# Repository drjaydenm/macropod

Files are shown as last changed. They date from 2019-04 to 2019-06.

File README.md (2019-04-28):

# macropod

A basic macro keyboard built from the ground up

## Configuring Macros

To setup your own macro bindings, create a file `key_mappings.h` in the `code/src` directory with the below format. This file will be automatically detected and included in the build.

When editing, be sure to do a clean build to ensure headers are re-included.

```c
#ifndef __KEY_MAPPINGS_H
#define __KEY_MAPPINGS_H

// This will generate a unique GUID following the V4 spec
#define MACRO_KEY_0  GenerateGuid(MacroContext);WriteString(MacroContext, "\e")

// These output the given string
#define MACRO_KEY_1  WriteString(MacroContext, "Macro 1\n")
#define MACRO_KEY_2  GenerateGuid(MacroContext);WriteString(MacroContext, "\e\nMacro 2");
#define MACRO_KEY_3  WriteString(MacroContext, "\t\tMacro 3")
// And so on for the rest of the keys...

#endif
```

## Setup

### Install the GNU Toolchain for ARM Embedded Processors

The toolchain is required to compile for the STM32 target platform

#### MacOS

```bash
brew tap osx-cross/arm

brew install arm-gcc-bin
```

If you are using ST-Link

```bash
brew install stlink
```

If using J-Link, you also need to install the J-Link tools. You can download them from Segger here https://www.segger.com/downloads/jlink/#J-LinkSoftwareAndDocumentationPack

## Building

Run the build

```bash
make
```

Flash to device using ST-Link

```bash
make flash-stlink
```

or using J-Link

```bash
make flash-jlink
```

Inspect memory layout of image

```bash
arm-none-eabi-nm main.elf
```

## Debugging with GDB

### ST-Link GDB Server

```bash
st-util
```

### J-Link GDB Server

```bash
JLinkGDBServer -if swd -device STM32F042K6 -port 4242
```

### GDB

```bash
cd ./code

arm-none-eabi-gdb main.elf

target extended-remote :4242

load

continue

Ctrl^C

info registers

stepi

info registers

quit
```

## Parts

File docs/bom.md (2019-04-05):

| Part | Quantity | Part No. | Price | Link |
| --- | --- | --- | --- | --- |
| STM32F042K6T6 | 1 | 497-14647-ND | $4.15 | https://www.digikey.com.au/product-detail/en/stmicroelectronics/STM32F042K6T6/497-14647-ND/4815294 |
| 1N4148W-TP Diode | 20 | 1N4148WTPMSCT-ND | $0.125 | https://www.digikey.com.au/product-detail/en/micro-commercial-co/1N4148W-TP/1N4148WTPMSCT-ND/717311 |
| Cherry MX Blue | 20 | MX1A-E1NA | $10 per 10 | https://mechanicalkeyboards.com/shop/index.php?l=product_detail&p=4450 |
| DSA Key Caps | 20 | | | https://www.aliexpress.com/item/MP-1U-DSA-keys-PBT-Blank-Keycap-Mixded-Color-Cherry-MX-switch-keycaps-for-Wired-USB/32847751930.html |
| LED SMD Blue | 1 | 732-4982-1-ND | $0.18 | https://www.digikey.com.au/product-detail/en/wurth-electronics-inc/150080BS75000/732-4982-1-ND/4489910 |
| JTAG 10 Pin 1.27mm | 1 | 609-3695-1-ND | $1.23 | https://www.digikey.com.au/product-detail/en/amphenol-icc-fci/20021121-00010C4LF/609-3695-1-ND/2209147 |
| 5.6Ohm Resistor | 1 | P5.6ACT-ND | $0.15 | https://www.digikey.com.au/product-detail/en/panasonic-electronic-components/ERJ-6GEYJ5R6V/P5.6ACT-ND/282468 |
| 0.1uF Capacitor | 3 | 1276-1099-1-ND | $0.15 | https://www.digikey.com.au/product-detail/en/samsung-electro-mechanics/CL21B104KACNNNC/1276-1099-1-ND/3889185 |
| 4.7uF Capacitor | 2 | 1276-6464-1-ND | $0.19 | https://www.digikey.com.au/product-detail/en/samsung-electro-mechanics/CL21A475KPFNNNG/1276-6464-1-ND/5958092 |
| USB Micro B Connector | 1 | WM11262CT-ND | $2.35 | https://www.digikey.com.au/product-detail/en/molex/1050171001/WM11262CT-ND/3313406 |
| 3.3V Regulator | 1 | 497-17239-1-ND | $0.66 | https://www.digikey.com.au/product-detail/en/stmicroelectronics/LDL1117S33R/497-17239-1-ND/7102079 |
| Tactile Switch | 1 | SW1020CT-ND | $1.47 | https://www.digikey.com.au/product-detail/en/omron-electronics-inc-emc-div/B3U-1000P/SW1020CT-ND/1534357 |
| Bumper Feet | 4 | SJ5003-0-ND | $7.83 per 56 | https://www.digikey.com.au/product-detail/en/3m/SJ-5003-BLACK/SJ5003-0-ND/102573 |

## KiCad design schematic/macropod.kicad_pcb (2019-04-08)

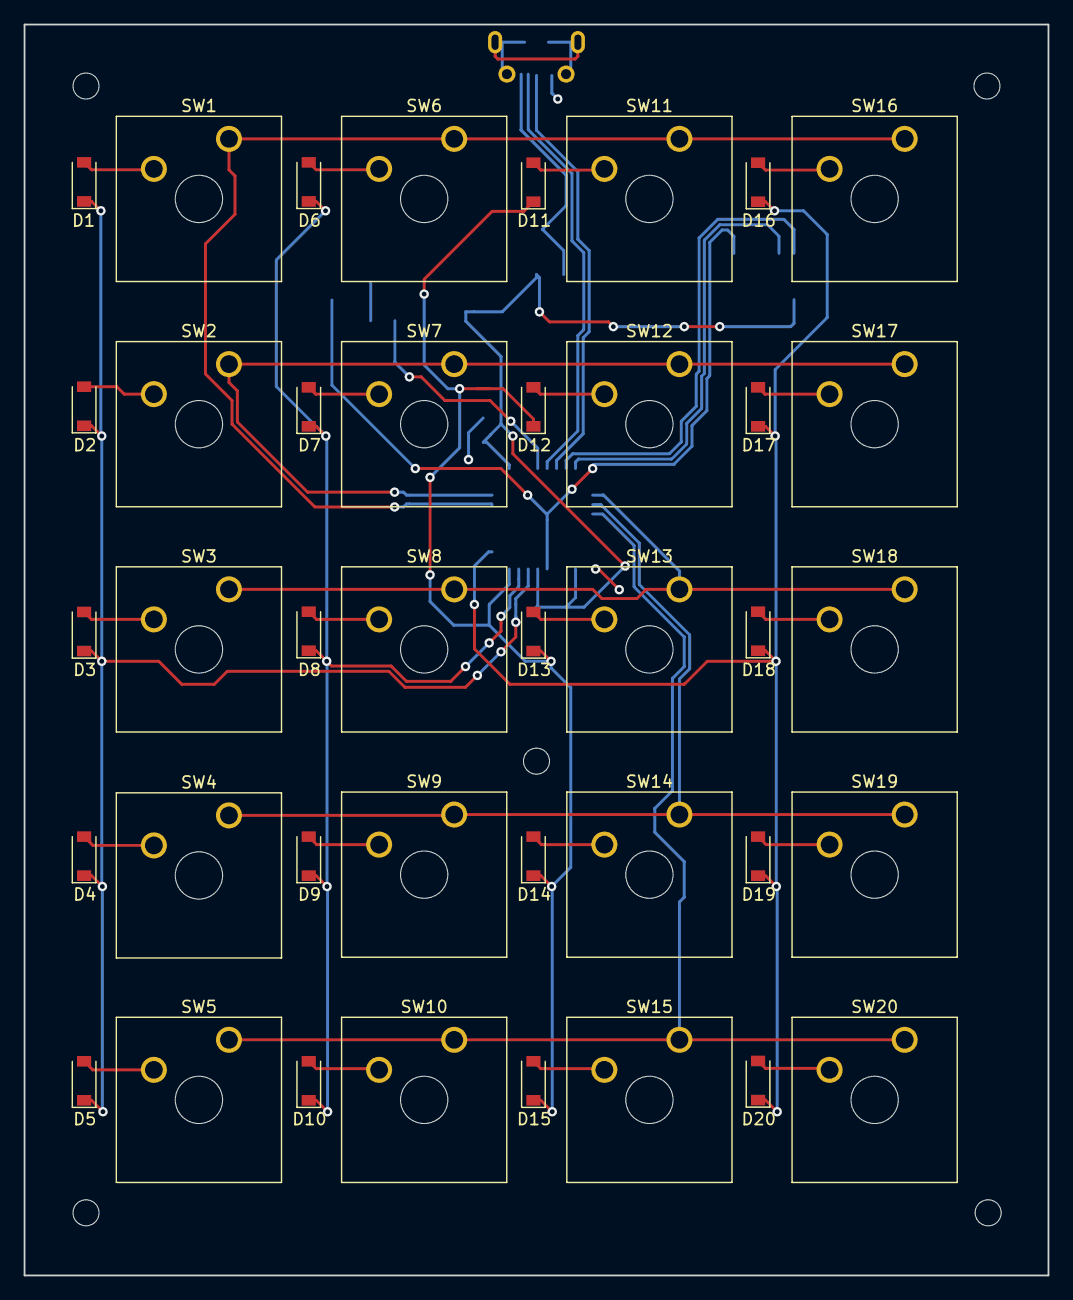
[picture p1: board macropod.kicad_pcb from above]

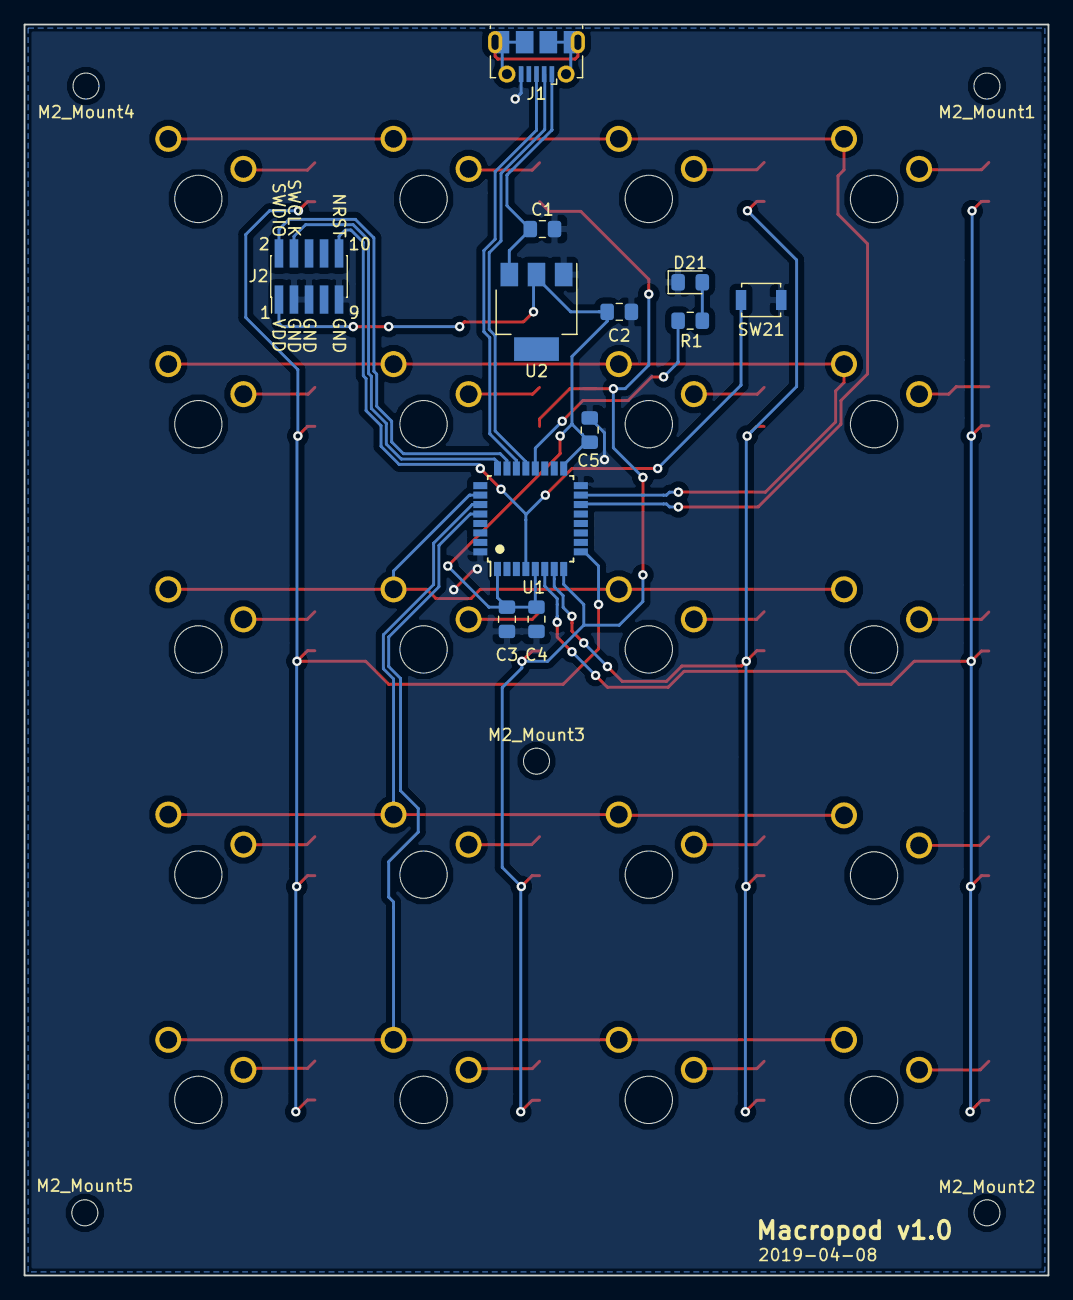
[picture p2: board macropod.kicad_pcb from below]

Board: 2 copper layers, 86.6 x 105.8 mm, 57 parts (17 on the bottom side), 39 nets.

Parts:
C1, C2: 4.7uF; C_0805_2012Metric_Pad1.15x1.40mm_HandSolder
C3, C4, C5: 100nF; C_0805_2012Metric_Pad1.15x1.40mm_HandSolder
D1, D2, D3, D4, D5, D6, D7, D8, D9, D10, D11, D12, D13, D14, D15, D16, D17, D18, D19, D20: D; D_SOD-123
D21: LED; LED_0805_2012Metric_Pad1.15x1.40mm_HandSolder
J1: USB_B_Micro; USB_Micro-B_Molex-105017-0001
J2: Conn_ARM_JTAG_SWD_10; PinHeader_2x05_P1.27mm_Vertical_SMD
M2_Mount1, M2_Mount2, M2_Mount3, M2_Mount4, M2_Mount5: MountingHole_2.2mm_M2
R1: 470; R_0805_2012Metric_Pad1.15x1.40mm_HandSolder
SW1, SW2, SW3, SW4, SW5, SW6, SW7, SW8, SW9, SW10, SW11, SW12, SW13, SW14, SW15, SW16, SW17, SW18, SW19, SW20: SW_MK; SW_Cherry_MX1A_1.00u_Plate
SW21: SW_SPST; SW_SPST_B3U-1000P
U1: STM32F042K6Tx; LQFP-32_7x7mm_P0.8mm
U2: LM1117-3.3; SOT-223

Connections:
/COL0: D1.1, D2.1, D3.1, D4.1, D5.1, U1.6
/COL1: D6.1, D7.1, D8.1, D9.1, D10.1, U1.7
/COL2: D11.1, D12.1, D13.1, D14.1, D15.1, U1.8
/COL3: D16.1, D17.1, D18.1, D19.1, D20.1, U1.9
/NRST: J2.10, SW21.2, U1.4
/PWR_LED: R1.1, U1.20
/ROW0: SW1.1, SW6.1, SW11.1, SW16.1, U1.14
/ROW1: SW2.1, SW7.1, SW12.1, SW17.1, U1.15
/ROW2: SW3.1, SW8.1, SW13.1, SW18.1, U1.26
/ROW3: SW4.1, SW9.1, SW14.1, SW19.1, U1.27
/ROW4: SW5.1, SW10.1, SW15.1, SW20.1, U1.28
/SWCLK: J2.4, U1.24
/SWDIO: J2.2, U1.23
/USBD+: J1.3, U1.22
/USBD-: J1.2, U1.21
/VBUS: C1.1, J1.1, U2.3
/VDD: C2.1, C3.1, C4.1, C5.1, J2.1, U1.1, U1.5, U1.17, U2.2
GND: C1.2, C2.2, C3.2, C4.2, C5.2, D21.1, J1.5, J2.3, J2.5, J2.9, SW21.1, U1.16, U1.32, U2.1
unnamed: D1.2, SW1.2
unnamed: D2.2, SW2.2
unnamed: D3.2, SW3.2
unnamed: D4.2, SW4.2
unnamed: D5.2, SW5.2
unnamed: D6.2, SW6.2
unnamed: D7.2, SW7.2
unnamed: D8.2, SW8.2
unnamed: D9.2, SW9.2
unnamed: D10.2, SW10.2
unnamed: D11.2, SW11.2
unnamed: D12.2, SW12.2
unnamed: D13.2, SW13.2
unnamed: D14.2, SW14.2
unnamed: D15.2, SW15.2
unnamed: D16.2, SW16.2
unnamed: D17.2, SW17.2
unnamed: D18.2, SW18.2
unnamed: D19.2, SW19.2
unnamed: D20.2, SW20.2
unnamed: D21.2, R1.2

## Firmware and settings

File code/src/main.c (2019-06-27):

#include "main.h"

int main()
{
    HAL_Init();

    SystemClockConfig();

    SetupGPIO();
    SetupKeyboard();

    uint32_t lastFlashMillis = HAL_GetTick();
    uint32_t lastPauseMillis = HAL_GetTick();
    while (1)
    {
        ScanKeyboard();
        UpdateKeyboard();

        uint32_t millis = HAL_GetTick();
        if (millis - lastPauseMillis >= PAUSE_MILLIS)
        {
            HAL_GPIO_WritePin(GPIOA, GPIO_PIN_10, GPIO_PIN_SET);

            if (millis - lastFlashMillis >= PAUSE_MILLIS + FLASH_MILLIS)
            {
                lastPauseMillis = millis;
                lastFlashMillis = millis;
                HAL_GPIO_WritePin(GPIOA, GPIO_PIN_10, GPIO_PIN_RESET);
            }
        }
    }
}

void SetupGPIO()
{
    static GPIO_InitTypeDef GPIO_InitStruct;

    __HAL_RCC_GPIOA_CLK_ENABLE();
    __HAL_RCC_GPIOB_CLK_ENABLE();
    __HAL_RCC_GPIOF_CLK_ENABLE();

    // Configure the onboard LED
    GPIO_InitStruct.Mode = GPIO_MODE_OUTPUT_PP;
    GPIO_InitStruct.Pull = GPIO_PULLUP;
    GPIO_InitStruct.Speed = GPIO_SPEED_FREQ_HIGH;
    GPIO_InitStruct.Pin = GPIO_PIN_10;

    HAL_GPIO_Init(GPIOA, &GPIO_InitStruct);
}

void SystemClockConfig(void)
{
    RCC_ClkInitTypeDef RCC_ClkInitStruct;
    RCC_OscInitTypeDef RCC_OscInitStruct;
    RCC_PeriphCLKInitTypeDef PeriphClkInitStruct;
    RCC_CRSInitTypeDef RCC_CRSInitStruct;

    // Enable HSI48 Oscillator to be used as system clock source
    RCC_OscInitStruct.OscillatorType = RCC_OSCILLATORTYPE_HSI48;
    HAL_RCC_OscConfig(&RCC_OscInitStruct);

    // Select HSI48 as USB clock source
    PeriphClkInitStruct.PeriphClockSelection = RCC_PERIPHCLK_USB;
    PeriphClkInitStruct.UsbClockSelection = RCC_USBCLKSOURCE_HSI48;
    HAL_RCCEx_PeriphCLKConfig(&PeriphClkInitStruct);

    // Select HSI48 as the system clock source, and configure HCLK and PCLK1 clock dividers
    RCC_ClkInitStruct.ClockType = (RCC_CLOCKTYPE_SYSCLK | RCC_CLOCKTYPE_HCLK | RCC_CLOCKTYPE_PCLK1);
    RCC_ClkInitStruct.SYSCLKSource = RCC_SYSCLKSOURCE_HSI48;
    RCC_ClkInitStruct.AHBCLKDivider = RCC_SYSCLK_DIV1;
    RCC_ClkInitStruct.APB1CLKDivider = RCC_HCLK_DIV1;
    HAL_RCC_ClockConfig(&RCC_ClkInitStruct, FLASH_LATENCY_1);

    __HAL_RCC_CRS_CLK_ENABLE();

    RCC_CRSInitStruct.Prescaler = RCC_CRS_SYNC_DIV1;
    RCC_CRSInitStruct.Source = RCC_CRS_SYNC_SOURCE_USB;
    RCC_CRSInitStruct.ReloadValue = __HAL_RCC_CRS_RELOADVALUE_CALCULATE(48000000, 1000);
    RCC_CRSInitStruct.ErrorLimitValue = RCC_CRS_ERRORLIMIT_DEFAULT;
    RCC_CRSInitStruct.HSI48CalibrationValue = 0x20;
    HAL_RCCEx_CRSConfig(&RCC_CRSInitStruct);

    __HAL_RCC_PWR_CLK_ENABLE();
}

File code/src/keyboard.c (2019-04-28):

#include "keyboard.h"

GPIOPin rows[] =
{
    { GPIOB, GPIO_PIN_0 },
    { GPIOB, GPIO_PIN_1 },
    { GPIOB, GPIO_PIN_3 },
    { GPIOB, GPIO_PIN_4 },
    { GPIOB, GPIO_PIN_5 }
};
const uint8_t rowCount = sizeof(rows) / sizeof(rows[0]);
GPIOPin columns[] =
{
    { GPIOA, GPIO_PIN_0 },
    { GPIOA, GPIO_PIN_1 },
    { GPIOA, GPIO_PIN_2 },
    { GPIOA, GPIO_PIN_3 }
};
const uint8_t columnCount = sizeof(columns) / sizeof(columns[0]);

KeyboardKey keys[] =
{
    // Row 0
    { KEY_MACRO_0, KEY_STATE_UP },
    { KEY_MACRO_1, KEY_STATE_UP },
    { KEY_MACRO_2, KEY_STATE_UP },
    { KEY_MACRO_3, KEY_STATE_UP },
    // Row 1
    { KEY_MACRO_4, KEY_STATE_UP },
    { KEY_MACRO_5, KEY_STATE_UP },
    { KEY_MACRO_6, KEY_STATE_UP },
    { KEY_MACRO_7, KEY_STATE_UP },
    // Row 2
    { KEY_MACRO_8, KEY_STATE_UP },
    { KEY_MACRO_9, KEY_STATE_UP },
    { KEY_MACRO_10, KEY_STATE_UP },
    { KEY_MACRO_11, KEY_STATE_UP },
    // Row 3
    { KEY_MACRO_12, KEY_STATE_UP },
    { KEY_MACRO_13, KEY_STATE_UP },
    { KEY_MACRO_14, KEY_STATE_UP },
    { KEY_MACRO_15, KEY_STATE_UP },
    // Row 4
    { KEY_MACRO_16, KEY_STATE_UP },
    { KEY_MACRO_17, KEY_STATE_UP },
    { KEY_MACRO_18, KEY_STATE_UP },
    { KEY_MACRO_19, KEY_STATE_UP }
};
const uint8_t keyCount = sizeof(keys) / sizeof(keys[0]);

uint8_t macroKeyDown = 0;
uint8_t macroStep = 0;
uint8_t macroNextKeySame = 0;
uint32_t macroMillis = 0;
MacroContext macroContext = {0};

void SetupKeyboard() {
    static GPIO_InitTypeDef GPIO_InitStruct;

    AnyKeyDown = 0;

    USBD_Init(&USBD_Device, &HID_Desc, 0);
    USBD_RegisterClass(&USBD_Device, &USBD_HID);
    USBD_Start(&USBD_Device);
    
    // Configure the scan line pins for input
    for (int i = 0; i < rowCount; i++)
    {
        GPIO_InitStruct.Mode = GPIO_MODE_INPUT;
        GPIO_InitStruct.Pull = GPIO_PULLUP;
        GPIO_InitStruct.Speed = GPIO_SPEED_FREQ_LOW;
        GPIO_InitStruct.Pin = rows[i].Pin;

        HAL_GPIO_Init(rows[i].Port, &GPIO_InitStruct);
    }
    for (int i = 0; i < columnCount; i++)
    {
        GPIO_InitStruct.Mode = GPIO_MODE_OUTPUT_PP;
        GPIO_InitStruct.Pull = GPIO_PULLUP;
        GPIO_InitStruct.Speed = GPIO_SPEED_FREQ_LOW;
        GPIO_InitStruct.Pin = columns[i].Pin;

        HAL_GPIO_Init(columns[i].Port, &GPIO_InitStruct);
        HAL_GPIO_WritePin(columns[i].Port, columns[i].Pin, GPIO_PIN_SET);
    }
}

void ScanKeyboard() {
    // Only scan for key states if we aren't processing a macro
    if (!macroKeyDown)
    {
        ScanKeys();
    }
}

void UpdateKeyboard() {
    if (macroKeyDown)
    {
        HandleMacroKey();
    }
    else
    {
        HandleStandardKeys();
    }
}

void ScanKeys()
{
    uint32_t millis = HAL_GetTick();
    uint8_t keyIndex = 0;
    AnyKeyDown = 0;

    for (uint8_t i = 0; i < columnCount; i++)
    {
        HAL_GPIO_WritePin(columns[i].Port, columns[i].Pin, GPIO_PIN_RESET);

        for (uint8_t j = 0; j < rowCount; j++)
        {
            keyIndex = (columnCount * j) + i;

            KeyState keyState = HAL_GPIO_ReadPin(rows[j].Port, rows[j].Pin);
            if (keyState != keys[keyIndex].State)
            {
                if (millis - keys[keyIndex].StateChangeMillis > DEBOUNCE_MILLIS)
                {
                    keys[keyIndex].State = keyState;
                    keys[keyIndex].StateChangeMillis = millis;
                }
            }

            if (keys[keyIndex].State == KEY_STATE_DOWN)
            {
                AnyKeyDown = 1;
            }

            if (IS_MACRO_KEY(keys[keyIndex].Key) && keys[keyIndex].State == KEY_STATE_DOWN)
            {
                BeginMacroKey(keys[keyIndex]);
            }
        }

        HAL_GPIO_WritePin(columns[i].Port, columns[i].Pin, GPIO_PIN_SET);
    }
}

void BeginMacroKey(KeyboardKey key)
{
    macroKeyDown = key.Key;
    macroMillis = HAL_GetTick();

    GetKeyContent(key.Key, &macroContext);
}

void EndMacroKey()
{
    macroKeyDown = 0;
    macroStep = 0;
    macroContext.Length = 0;
    macroNextKeySame = 0;

    // Zero out the macro content
    memset(macroContext.Content, 0, MACRO_BUFFER_SIZE);
}

void HandleStandardKeys()
{
    uint8_t currentReportKey = 0;
    HIDKeyboardReport report = {0};

    if (!AnyKeyDown)
    {
        SendNullReport();
        return;
    }

    for (int i = 0; i < keyCount; i++)
    {
        if (keys[i].State == KEY_STATE_DOWN)
        {
            report.Keys[currentReportKey] = keys[i].Key;
            currentReportKey++;
        }

        // We can only send up to REPORT_MAX_KEYS keys at once
        if (currentReportKey >= REPORT_MAX_KEYS)
        {
            break;
        }
    }

    SendReport(&report);
}
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

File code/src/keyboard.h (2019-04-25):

#ifndef __KEYBOARD_H
#define __KEYBOARD_H

#include "usbd_desc.h"
#include "usbd_hid.h"
#include "gpio_pin.h"
#include "keys.h"
#include "macros.h"

#define REPORT_BUF_SIZE 8
#define REPORT_MAX_KEYS 6
#define DEBOUNCE_MILLIS 30
#define MACRO_KEY_DELAY 20
#define POST_MACRO_DELAY 500

typedef struct
{
    uint8_t Modifiers;
    uint8_t Keys[REPORT_MAX_KEYS];
}
HIDKeyboardReport;

typedef enum
{
    KEY_STATE_DOWN = 0,
    KEY_STATE_UP = 1
}
KeyState;

typedef struct
{
    uint8_t Key;
    KeyState State;
    uint32_t StateChangeMillis;
}
KeyboardKey;

__ALIGN_BEGIN uint8_t _reportBuffer[REPORT_BUF_SIZE] __ALIGN_END;
USBD_HandleTypeDef USBD_Device;
uint8_t AnyKeyDown;

void SetupKeyboard();
void ScanKeyboard();
void UpdateKeyboard();
void ScanKeys();
void BeginMacroKey(KeyboardKey key);
void EndMacroKey();
void HandleStandardKeys();
void HandleMacroKey();
void SendNullReport();
void SendReport(const HIDKeyboardReport* report);
void CopyReportToBuffer(const HIDKeyboardReport* report, uint8_t* buffer);
void ResetReport(HIDKeyboardReport* report);

#endif

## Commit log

2019-04-04 Added macropod schematics
    [keys.sch, macropod.kicad_pcb, macropod.sch]
2019-04-04 Added the bill of materials
2019-04-05 Added switch and bumper feet to BOM
2019-04-08 Updated footprints to match BOM components. Applied DRC settings for fabrication
    [keys.sch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]
2019-04-25 Updated keyboard to use a matrix instead of a key per pin. Started GPIO clocks before configuring pins
2019-04-25 Added an optional header file to declare key mappings to macros. Fixed upper case letters and handled the shift key
    [keyboard.c, keyboard.h]
